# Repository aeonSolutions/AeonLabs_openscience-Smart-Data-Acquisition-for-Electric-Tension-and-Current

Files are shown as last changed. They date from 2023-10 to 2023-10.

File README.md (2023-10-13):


  
 
 

<a href="https://trackgit.com">
trackgit-views
</a>




[](https://www.buymeacoffee.com/migueltomas)

[PCB-Prototyping-Catalogue](https://github.com/aeonSolutions/PCB-Prototyping-Catalogue)  >>  [Laboratory Automation](https://github.com/aeonSolutions/PCB-Prototyping-Catalogue/tree/main/Laboratory%20Automation)  >>  Smart Data Acquisition for Electric Tension and Current

<br>

# Smart Data Acquisition for Electric Tension and Current
This is the repository for revision "11-2023" of the 16-bit Smart DAQ Device with a unique data fingerprint able to do experimental data upload to any data repository. This data acquisition device has oboard the INA237 IC and is suited for electric current measurements (amperage) and also electric tension (voltage) from an external power source. This IC from Texas Instruments is an ultra-precise digital power monitor with a 16-bit delta-sigma ADC specifically designed for current-sensing applications with common-mode voltage support from –0.3 V to +85 V. For more detailed information about this IC, see the datasheet [here](https://www.ti.com/product/INA237).

<p align="center">
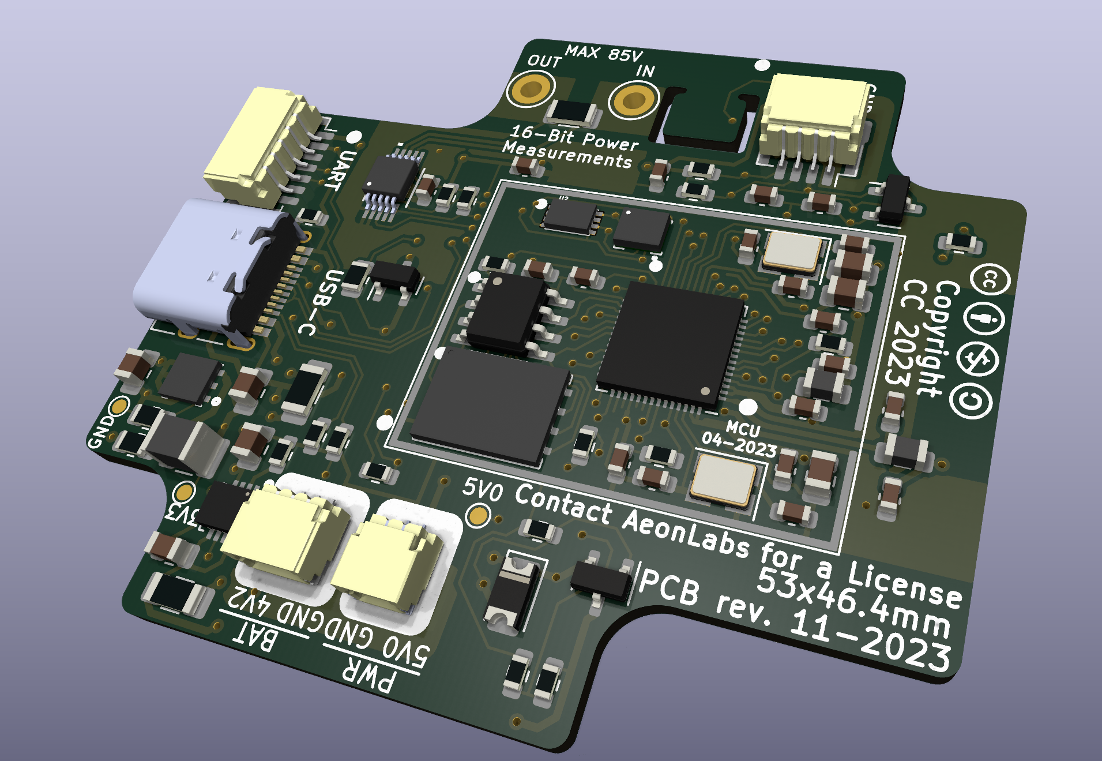
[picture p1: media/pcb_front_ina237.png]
   
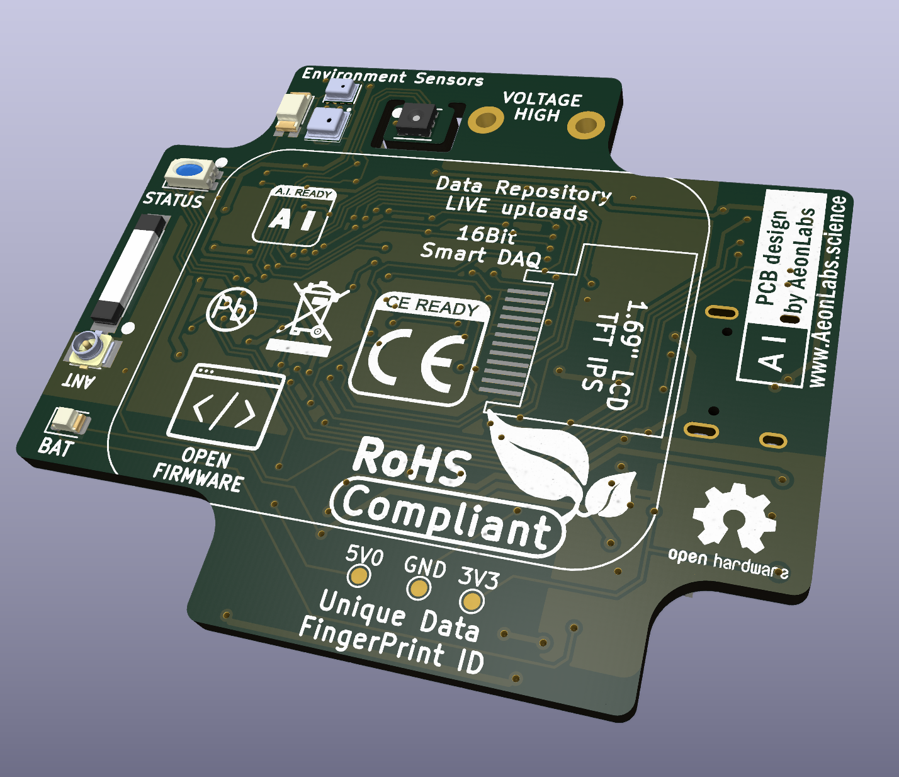
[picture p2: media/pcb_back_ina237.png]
   
</p>

<br>

### Circuit Schematic
The circuit schematic for this smart DAQ can be found on the folder "circuit schematic" [here](https://github.com/aeonSolutions/AeonLabs_openscience-Smart-Data-Acquisition-for-Electric-Tension-and-Current/tree/main/Circuit%20Schematic). 
<p align="center">
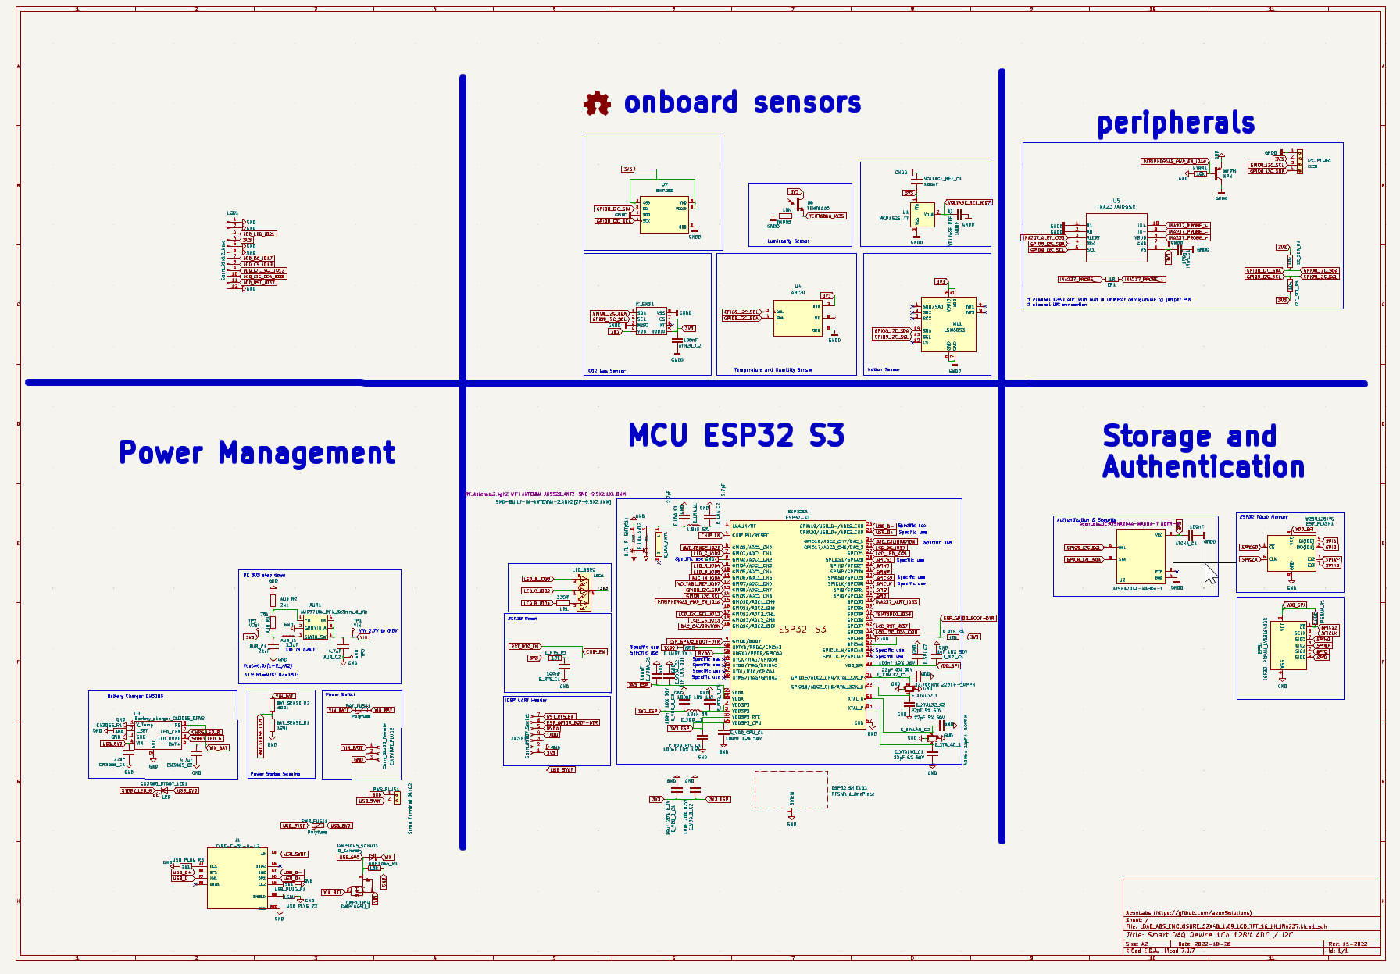
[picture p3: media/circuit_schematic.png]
   
</p>

<br>

### Q & A
If you have a question and looking for an answer, there's a **Discussions** chat on the menu above.  Here's the [link](https://github.com/aeonSolutions/AeonLabs_openscience-Smart-Data-Acquisition-for-Electric-Tension-and-Current/discussions). You can post any question related to any of the Smart Data Acquisition devices and Experimental Setups.

<br>

### Known Experimental Tests
This smart data acquisition devices is compatible for the following laboratory experimental tests:

#### [NT Build 492](http://www.nordtest.info/wp/1999/11/21/concrete-mortar-and-cement-based-repair-materials-chloride-migration-coefficient-from-non-steady-state-migration-experiments-n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): Concrete, mortar and cement-based repair materials: Chloride migration coefficient from non-steady-state migration experiments

<p align="center">
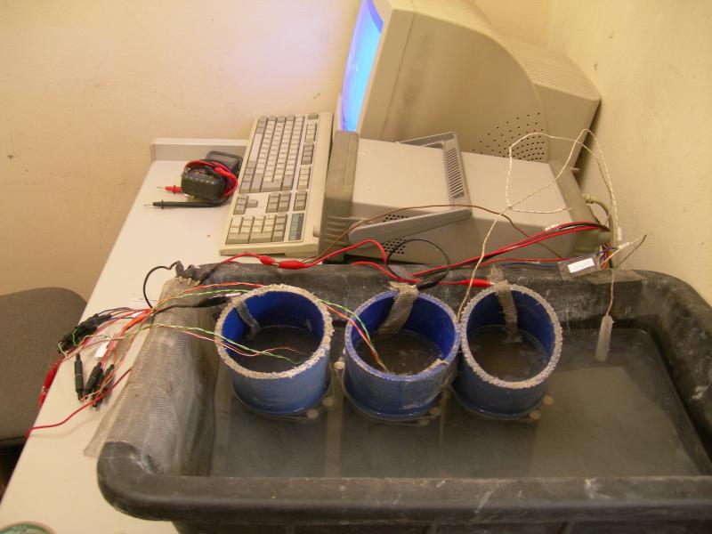
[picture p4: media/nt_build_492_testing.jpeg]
   
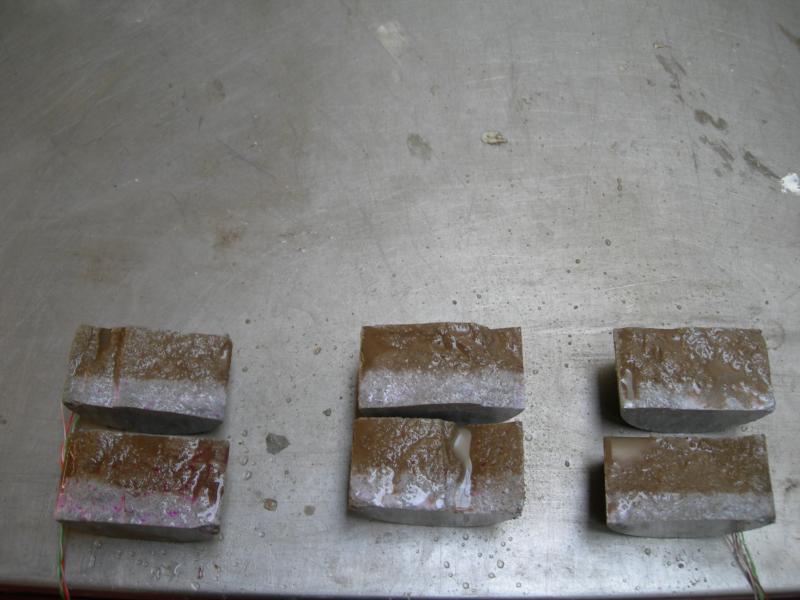
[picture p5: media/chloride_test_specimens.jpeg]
   
</p>

See [here](https://github.com/aeonSolutions/Open-Scientific-Research/wiki/Rapid-Chloride-Migration-Test-(NT-Build-492)) a description of this experimental test procedure using the NT Build 492. 

<br>
  
#### other tests ...

<br>
<br>
 
## Compatibility

<p align="center">
 <a href"https://www.apple.com/shop/accessories/all/homekit">

 </a>
<a href="https://home.google.com"> 
 
 </a>
<a href="https://www.home-assistant.io">  
 
 </a>
<a href="https://csa-iot.org/all-solutions/matter/">  
 
 </a>
<a href="https://csa-iot.org/all-solutions/matter/">  
 
 </a>
</p>

<br>

## What one additionally needs
- [USB to UART/USB TTL firmware burner for 5V and 3.3V MCUs ](https://github.com/aeonSolutions/PCB-Prototyping-Catalogue/blob/main/DIY-Maker/README.md)
- [Upgradable ESP32 MCU](https://github.com/aeonSolutions/AeonLabs-Upgradable-MCU-ESP32)

<br />
<br />

**Get a Notification on every PCB update**

| [](https://www.tindie.com/stores/aeonlabs/) | You can fill in your [email here (Google form)](https://docs.google.com/forms/d/e/1FAIpQLScErMgQYRdA-umvCjvTPPrCO7Lg1QYowTxb7vfa8cTfrcPEAA/viewform?usp=pp_url) and I'll send a reminder when a new PCB prototype is made available here or a new revision for an existing PCB. Stay tuned! |
|---|---|

<br>
<br>

## Author

You can get in touch with me on my LinkedIn Profile:

#### Miguel Tomas



You can also follow my GitHub Profile to stay updated about my latest projects: 

**Hire me**

If you like my work here and are looking to design and deploy your own smart device you can hire me on:

- [Fiverr](https://www.fiverr.com/s/GjmPxe). The price starts at $25
- [Guru](https://www.guru.com/freelancers/miguel-tomas)
  
<br>

### Be supportive of my dedication and work towards technology education and buy me a cup of coffee
The PCB Desgin Files i provide here for anyone to use are free. If you like this Smart Device or use it, please consider buying me a cup of coffee, a slice of pizza or a book to help me study, eat and think new PCB design files.

[](https://www.buymeacoffee.com/migueltomas)

<br />

### Make a donation on Paypal
Make a donation on paypal and get a TAX refund*.

(http://paypal.me/mtpsilva)

<br>

### Support all these open hardware projects and become a patreon  
Liked any of my PCB KiCad Designs? Help and Support my open work to all by becomming a LDAD Patreon.
In return I will give a free PCB design in KiCad to all patreon supporters. To learn more go to patreon.com. Link below.

(https://www.patreon.com/ldad)

<br />
<br />

______________________________________________________________________________________________________________________________
### License

Before proceeding to download any of AeonLabs software solutions for open-source development and/or PCB hardware electronics development make sure you are choosing the right license for your project. See [AeonLabs Solutions for Open Hardware & Source Development](https://github.com/aeonSolutions/PCB-Prototyping-Catalogue/wiki/AeonLabs-Solutions-for-Open-Hardware-&-Source-Development) for more information.

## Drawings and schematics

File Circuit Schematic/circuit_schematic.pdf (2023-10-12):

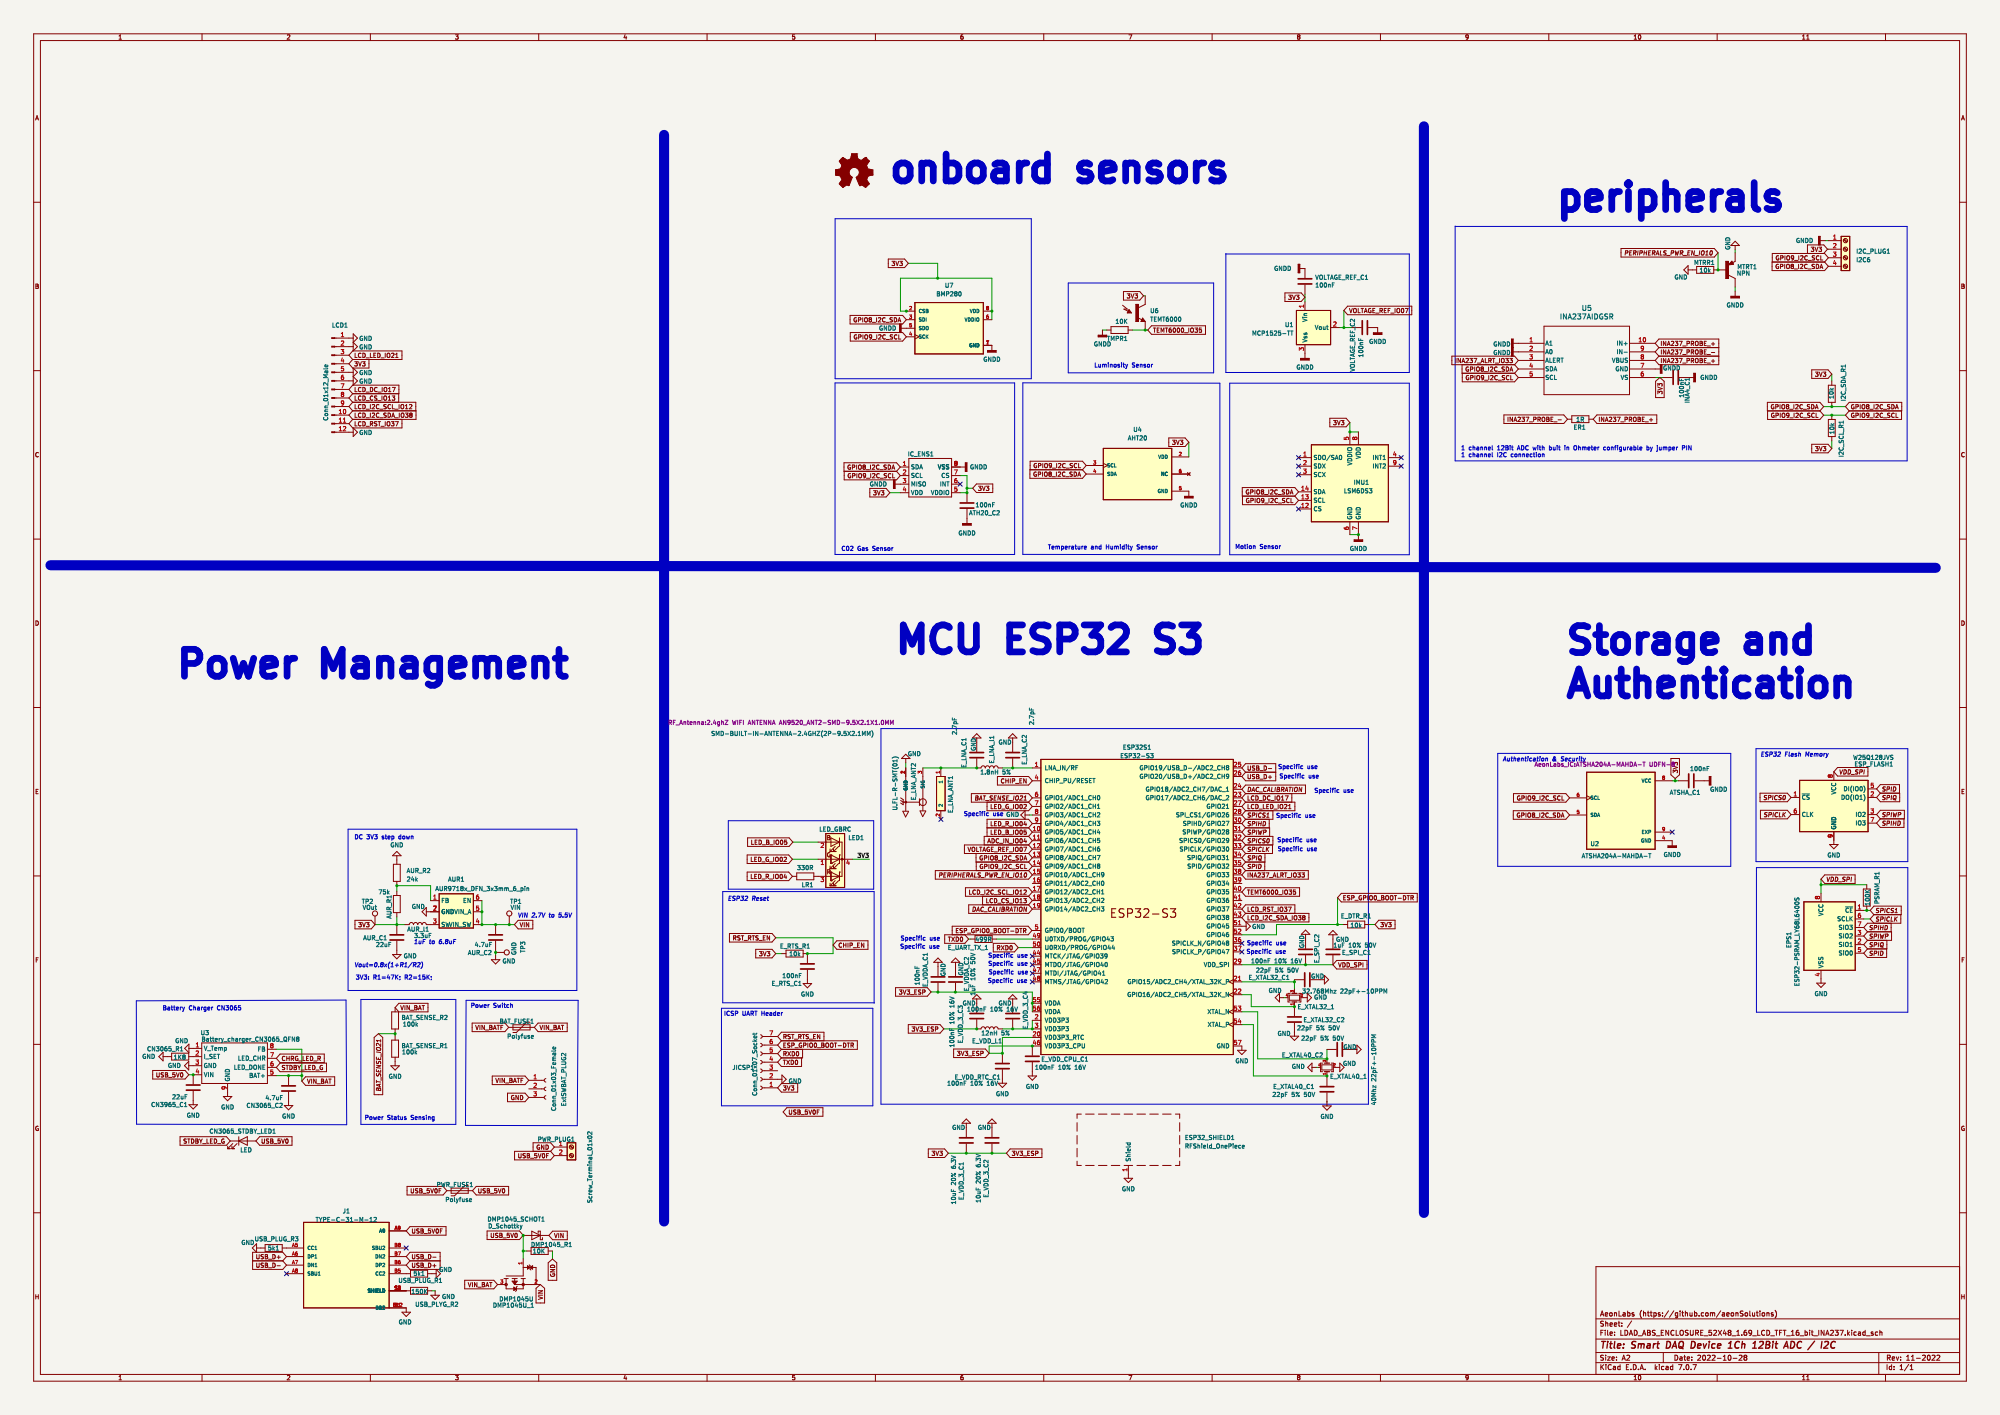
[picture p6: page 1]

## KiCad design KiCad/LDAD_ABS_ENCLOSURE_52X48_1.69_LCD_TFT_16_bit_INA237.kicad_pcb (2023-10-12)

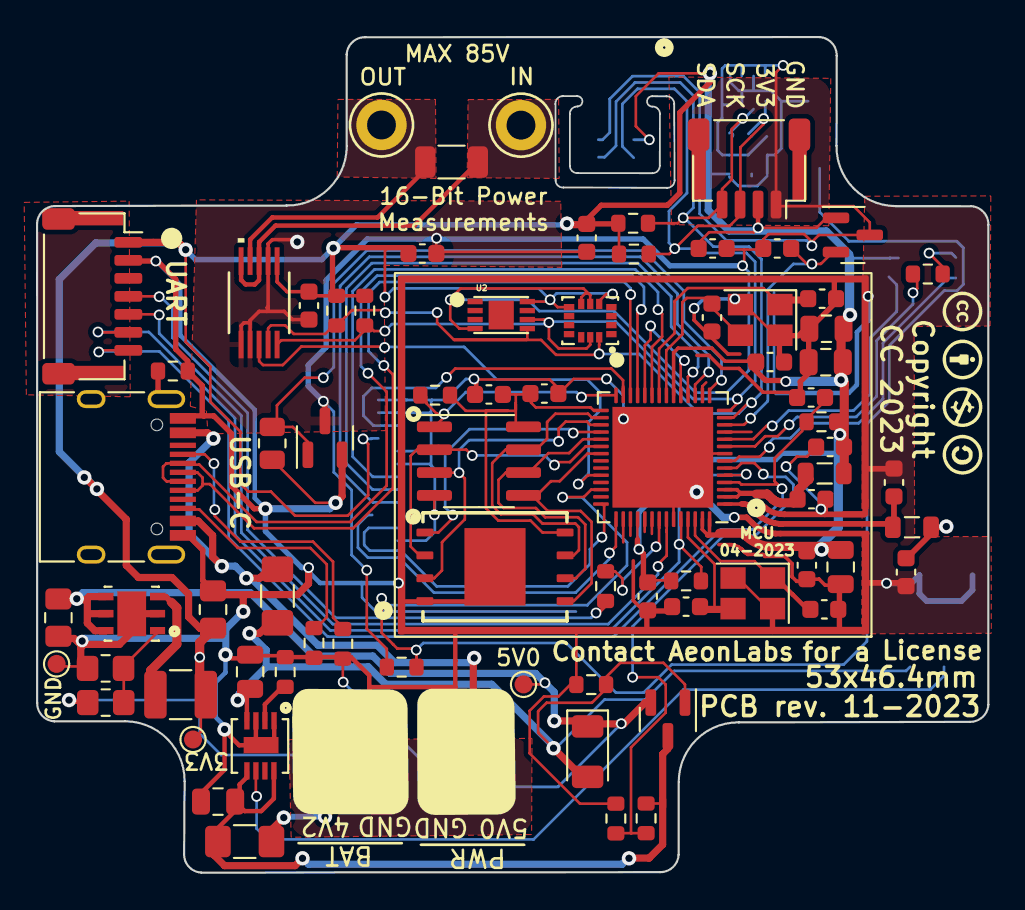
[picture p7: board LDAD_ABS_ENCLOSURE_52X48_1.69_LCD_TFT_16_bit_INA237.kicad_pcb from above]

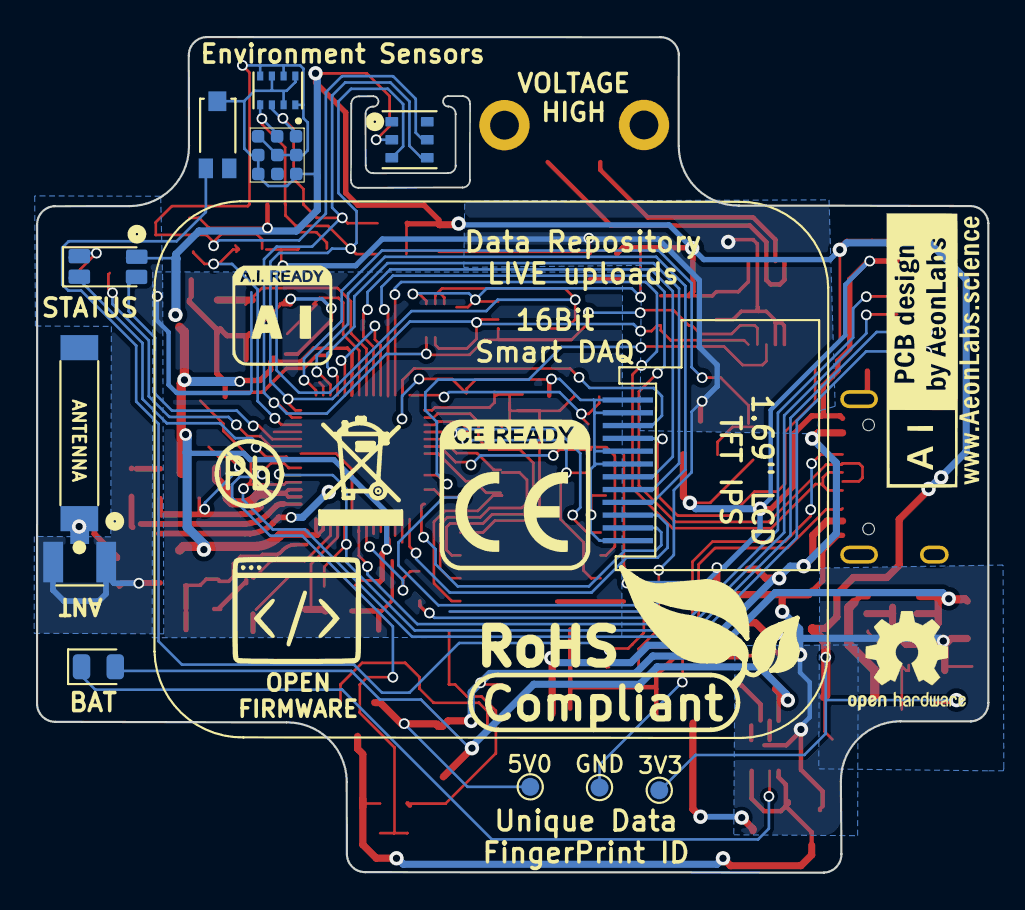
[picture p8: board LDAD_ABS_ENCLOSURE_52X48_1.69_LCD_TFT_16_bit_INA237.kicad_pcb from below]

Board: 2 copper layers, 52.9 x 46.4 mm, 90 parts (15 on the bottom side), 57 nets.

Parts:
ATH20_C2: 100nF; C_0603_1608Metric
ATSHA_C1: 100nF; C_0603_1608Metric
AUR1: AUR9718x_DFN_3x3mm_6_pin; AUR9718 ST1S09 SON95P300X300X100-7N
AUR_C1: 22uF; C_0805_2012Metric_Pad1.18x1.45mm_HandSolder
AUR_C2: 4.7uF; C_0805_2012Metric_Pad1.18x1.45mm_HandSolder
AUR_R1: 75k; R_0805_2012Metric_Pad1.20x1.40mm_HandSolder
AUR_R2: 24k; R_0805_2012Metric_Pad1.20x1.40mm_HandSolder
AUR_l1: 3.3uF; L_1210_3225Metric
BAT_FUSE1: Polyfuse; Fuse_1206_3216Metric_Pad1.42x1.75mm_HandSolder
BAT_SENSE_R1, BAT_SENSE_R2: 100k; R_0603_1608Metric
CN3065_C2: 4.7uF; C_0805_2012Metric
CN3065_R1: 1K8; R_0603_1608Metric
CN3065_STDBY_LED1: LED; LED_0805_2012Metric
CN3965_C1: 22uF; C_0805_2012Metric
DMP1045U_1: DMP1045U; SOT-23
DMP1045_R1: 10K; R_0603_1608Metric
DMP1045_SCHOT1: D_Schottky; D_1206_3216Metric
EPS1: ESP32-PSRAM_LY68L6400S; SOIC-8_3.9x4.9mm_P1.27mm
ER1: 1R; R_1206_3216Metric
ESP32S1: ESP32-S3; QFN-56-1EP_7x7mm_P0.4mm_EP5.6x5.6mm
ESP32_SHIELD1: RFShield_OnePiece; ESP32-S3 GND Shield
ESP_FLASH1: W25Q128JVS; WSON8 FLASH SPI SON127P800X600X80-9N
E_DTR_R1: 10k; R_0603_1608Metric
E_LNA_ANT1: AN9520; 2.4ghZ WIFI ANTENNA AN9520_ANT2-SMD-9.5X2.1X1.0MM
E_LNA_ANT2: U.FL-R-SMT(01); RF Antenna IPEX SMD PCB HRS_U.FL-R-SMT(01)
E_LNA_C1, E_LNA_C2: 2.7pF; C_0603_1608Metric
E_LNA_l1: 1.8nH 5%; L_0805_2012Metric
E_RTS_C1: 100nF; C_0603_1608Metric
E_RTS_R1: 10k; R_0603_1608Metric
E_SPI_C1: 1uF 10% 50V; C_0603_1608Metric
E_SPI_C2: 100nF 10% 16V; C_0603_1608Metric
E_UART_TX_1: 499R; R_0603_1608Metric
E_VDDA_C1: 100nF; C_0603_1608Metric
E_VDDA_C2: 1uF 10% 50V; C_0805_2012Metric
E_VDD_3_C1, E_VDD_3_C2: 10uF 20% 6.3V; C_0805_2012Metric
E_VDD_3_C3, E_VDD_3_C4: 100nF 10% 16V; C_0603_1608Metric
E_VDD_CPU_C1: 100nF 10% 16V; C_0603_1608Metric
E_VDD_L1: 12nH 5%; L_0805_2012Metric
E_VDD_RTC_C1: 100nF 10% 16V; C_0603_1608Metric
E_XTAL32_1: 32.768Mhz 22pF+-10PPM; Crystal_SMD_3225-4Pin_3.2x2.5mm
E_XTAL32_C1, E_XTAL32_C2, E_XTAL40_C1, E_XTAL40_C2: 22pF 5% 50V; C_0603_1608Metric
E_XTAL40_1: 40Mhz 22pF+-10PPM; Crystal_SMD_3225-4Pin_3.2x2.5mm
ExtSWBAT_PLUG2: Conn_01x03_Female; JST_SH_SM03B-SRSS-TB_1x03-1MP_P1.00mm_Horizontal
I2C_PLUG1: I2C6; JST_SH_SM04B-SRSS-TB_1x04-1MP_P1.00mm_Horizontal
I2C_SCL_R1, I2C_SDA_R1: 10k; R_0603_1608Metric
IC_ENS1: ENS160 Gas Semsor
IMR1, IMR2: 10K; R_0603_1608Metric
IMU1: LSM6DS3; LSM6DS3 Motion Sensor PQFN50P300X250X86-14N
INA4_C1: 100nF; C_0603_1608Metric
J1: TYPE-C-31-M-12; USB_C_Receptacle_HRO_TYPE-C-31-M-12
JICSP1: Conn_01x07_Socket; JST_SH_SM07B-SRSS-TB_1x07-1MP_P1.00mm_Horizontal
LCD1: Conn_01x12_Male; 1,69 inch LCD IPS TFT
LED1: LED_GBRC; LED_1206_3210_RGB_Metric
LR1: 330R; R_0603_1608Metric
MTRR1: 10k; R_0805_2012Metric
MTRT1: NPN; SOT-23
PSRAM_R1: 100K; R_0603_1608Metric
PWR_FUSE1: Polyfuse; Fuse_1206_3216Metric_Pad1.42x1.75mm_HandSolder
PWR_PLUG1: Screw_Terminal_01x02; JST_SH_SM02B-SRSS-TB_1x02-1MP_P1.00mm_Horizontal
Sign-PbFree: LOGO_PBFREE
Sign-RecycleBin: LOGO_RECYCLEBIN_1
Sign-RoHS: LOGO_ROHS_1
TMPR1: 10K; R_0603_1608Metric
TP1, TP1#2: VIN; TestPoint_Pad_D1.0mm
TP2, TP2#2: VOut; TestPoint_Pad_D1.0mm
TP3, TP3#2: GND; TestPoint_Pad_D1.0mm
U1: MCP1525-TT; SOT-23
U2: ATSHA204A-MAHDA-T; ATSHA204A-MAHDA-T UDFN-8
U3: Battery_charger_CN3065_QFN8; QFN8 3.1x2.9mm QFNn-8 3x3 SON80P400X400X100-9N
U4: AHT20; AHT20 HT Sensor PSON100P300X300X110-6N
U5: INA237AIDGSR; INA237
U6: TEMT6000; TEMT6000-SEN
U7: BMP280; XDCR_BMP280
USB_PLUG_R1, USB_PLUG_R3: 5k1; R_0603_1608Metric
USB_PLYG_R2: 150K; R_0603_1608Metric
VOLTAGE_REF_C1, VOLTAGE_REF_C2: 100nF; C_0603_1608Metric

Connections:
3V3: ATH20_C2.2, ATSHA_C1.2, AUR_C1.1, AUR_R1.1, AUR_l1.1, ESP32S1.20 (VDD3P3_RTC), ESP32S1.46 (VDD3P3_CPU), ESP32S1.55 (VDDA), ESP32S1.56 (VDDA), E_DTR_R1.1, E_RTS_R1.1, E_VDDA_C1.2, E_VDDA_C2.2, E_VDD_3_C1.1, E_VDD_3_C2.1, E_VDD_3_C3.1, E_VDD_CPU_C1.1, E_VDD_L1.1, E_VDD_RTC_C1.1, I2C_PLUG1.2, I2C_SCL_R1.1, I2C_SDA_R1.2, IC_ENS1.4 (VDD), IC_ENS1.5 (VDDIO), IC_ENS1.7 (CS), IMR1.1, IMR2.1, IMU1.5 (VDDIO), IMU1.8 (VDD), INA4_C1.2, JICSP1.1, LCD1.4, LED1.4 (K), TP2.1, TP2#2.1, U1.1 (Vin), U2.8 (VCC), U4.2 (VDD), U5.6 (VS), U6.COLLECTOR, U7.2 (CSB), U7.6 (VDDIO), U7.8 (VDD), VOLTAGE_REF_C1.2
BAT_SENSE_IO21: BAT_SENSE_R1.1, BAT_SENSE_R2.2, ESP32S1.6 (GPIO1/ADC1_CH0)
CHIP_EN: ESP32S1.4 (CHIP_PU/RESET), E_RTS_C1.2, E_RTS_R1.2, JICSP1.7
DAC_CALIBRATION: ESP32S1.19 (GPIO14/ADC2_CH3), ESP32S1.24 (GPIO18/ADC2_CH7/DAC_1)
ESP_GPIO0_BOOT-DTR: ESP32S1.5 (GPIO0/BOOT), ESP32S1.52 (GPIO46), E_DTR_R1.2, JICSP1.6
GND: AUR1.2 (GND), AUR1.7 (GND), AUR_C1.2, AUR_C2.2, AUR_R2.2, BAT_SENSE_R1.2, CN3065_C2.1, CN3065_R1.1, CN3965_C1.1, DMP1045_R1.2, EPS1.4 (VSS), ESP32S1.8 (GPIO3/ADC1_CH2), ESP32S1.51 (GPIO45), ESP32S1.57 (GND), ESP32_SHIELD1.1 (Shield), ESP_FLASH1.4 (GND), ESP_FLASH1.9 (GND), E_LNA_ANT2.1 (GND), E_LNA_ANT2.2 (GND), E_LNA_C1.2, E_LNA_C2.2, E_RTS_C1.1, E_SPI_C1.2, E_SPI_C2.2, E_VDDA_C1.1, E_VDDA_C2.1, E_VDD_3_C1.2, E_VDD_3_C2.2, E_VDD_3_C3.2, E_VDD_3_C4.2, E_VDD_CPU_C1.2, E_VDD_RTC_C1.2, E_XTAL32_1.2, E_XTAL32_1.4, E_XTAL32_C1.2, E_XTAL32_C2.2, E_XTAL40_1.2, E_XTAL40_1.4, E_XTAL40_C1.2, E_XTAL40_C2.2, ExtSWBAT_PLUG2.3, J1.B1, J1.B12, JICSP1.2, LCD1.1, LCD1.2, LCD1.5, LCD1.6, LCD1.12, MTRR1.1, MTRT1.2, PWR_PLUG1.1, TP3.1, TP3#2.1, U3.1 (V_Temp), U3.3 (GND), U3.9 (GND), USB_PLUG_R1.2, USB_PLUG_R3.2, USB_PLYG_R2.2
GNDD: ATH20_C2.1, ATSHA_C1.1, I2C_PLUG1.1, IC_ENS1.3 (MISO), IC_ENS1.8 (VSS), IC_ENS1.9 (VSS), IMU1.6 (GND), IMU1.7 (GND), INA4_C1.1, MTRT1.3, TMPR1.1, U1.3 (Vss), U2.4 (GND), U4.5 (GND), U5.1 (A1), U5.2 (A0), U5.7 (GND), U7.1 (GND), U7.5 (SDO), U7.7 (GND), VOLTAGE_REF_C1.1, VOLTAGE_REF_C2.1
GPIO8_I2C_SDA: ESP32S1.13 (GPIO8/ADC1_CH7), I2C_PLUG1.4, I2C_SDA_R1.1, IC_ENS1.1 (SDA), IMR1.2, IMU1.14 (SDA), U2.5 (SDA), U4.4 (SDA), U5.4 (SDA), U7.3 (SDI)
GPIO9_I2C_SCL: ESP32S1.14 (GPIO9/ADC1_CH8), I2C_PLUG1.3, I2C_SCL_R1.2, IC_ENS1.2 (SCL), IMR2.2, IMU1.13 (SCL), U2.6 (SCL), U4.3 (SCL), U5.5 (SCL), U7.4 (SCK)
INA237_ALRT_IO33: ESP32S1.38 (GPIO33), U5.3 (ALERT)
INA237_PROBE_+: ER1.2, U5.8 (VBUS), U5.10 (IN+)
INA237_PROBE_-: ER1.1, U5.9 (IN-)
LCD_CS_IO13: ESP32S1.18 (GPIO13/ADC2_CH2), LCD1.8
LCD_DC_IO17: ESP32S1.23 (GPIO17/ADC2_CH6/DAC_2), LCD1.7
LCD_I2C_SCL_IO12: ESP32S1.17 (GPIO12/ADC2_CH1), LCD1.9
LCD_I2C_SDA_IO38: ESP32S1.43 (GPIO38), LCD1.10
LCD_LED_IO21: ESP32S1.27 (GPIO21), LCD1.3
LCD_RST_IO37: ESP32S1.42 (GPIO37), LCD1.11
LED_B_IO05: ESP32S1.10 (GPIO5/ADC1_CH4), LED1.2 (BA)
LED_G_IO02: ESP32S1.7 (GPIO2/ADC1_CH1), LED1.1 (GA)
LED_R_IO04: ESP32S1.9 (GPIO4/ADC1_CH3), LR1.1
unnamed: AUR1.1 (FB), AUR_R1.2, AUR_R2.1
unnamed: AUR1.3 (SW), AUR_l1.2
unnamed: ESP32S1.21 (GPIO15/ADC2_CH4/XTAL_32K_P), E_XTAL32_1.3, E_XTAL32_C1.1
unnamed: ESP32S1.22 (GPIO16/ADC2_CH5/XTAL_32K_N), E_XTAL32_1.1, E_XTAL32_C2.1
unnamed: ESP32S1.1 (LNA_IN/RF), E_LNA_C2.1, E_LNA_l1.2
unnamed: ESP32S1.49 (U0TXD/PROG/GPIO43), E_UART_TX_1.2
unnamed: ESP32S1.2 (VDD3P3), ESP32S1.3 (VDD3P3), E_VDD_3_C4.1, E_VDD_L1.2
unnamed: ESP32S1.53 (XTAL_N), E_XTAL40_1.3, E_XTAL40_C2.1
unnamed: ESP32S1.54 (XTAL_P), E_XTAL40_1.1, E_XTAL40_C1.1
unnamed: E_LNA_ANT1.1, E_LNA_ANT2.3 (SIG), E_LNA_C1.1, E_LNA_l1.1
unnamed: J1.A5 (CC1), USB_PLUG_R3.1
unnamed: J1.B5 (CC2), USB_PLUG_R1.1
unnamed: J1.S1 (SHIELD), USB_PLYG_R2.1
unnamed: LED1.3 (RA), LR1.2
unnamed: CN3065_R1.2, U3.2 (I_SET)
PERIPHERALS_PWR_EN_IO10: ESP32S1.15 (GPIO10/ADC1_CH9), MTRR1.2, MTRT1.1
RXD0: ESP32S1.50 (U0RXD/PROG/GPIO44), JICSP1.5
SPICLK: EPS1.6 (SCLK), ESP32S1.33 (SPICLK/GPIO30), ESP_FLASH1.6 (CLK)
SPICS0: ESP32S1.32 (SPICS0/GPIO29), ESP_FLASH1.1 (~CS)
SPICS1: EPS1.1 (~CE), ESP32S1.28 (SPI_CS1/GPIO26), PSRAM_R1.1
SPID: EPS1.5 (SiO0), ESP32S1.35 (SPID/GPIO32), ESP_FLASH1.5 (DI(IO0))
SPIHD: EPS1.7 (SIO3), ESP32S1.30 (SPIHD/GPIO27), ESP_FLASH1.7 (IO3)
SPIQ: EPS1.2 (SIO1), ESP32S1.34 (SPIQ/GPIO31), ESP_FLASH1.2 (DO(IO1))
SPIWP: EPS1.3 (SIO2), ESP32S1.31 (SPIWP/GPIO28), ESP_FLASH1.3 (IO2)
STDBY_LED_G: CN3065_STDBY_LED1.1 (K), U3.6 (LED_DONE)
TEMT6000_IO35: ESP32S1.40 (GPIO35), TMPR1.2, U6.EMITTER
TXD0: E_UART_TX_1.1, JICSP1.4
USB_5V0: CN3065_STDBY_LED1.2 (A), CN3965_C1.2, DMP1045U_1.1, DMP1045_R1.1, DMP1045_SCHOT1.2 (A), PWR_FUSE1.1, U3.4 (VIN)
USB_5V0F: J1.A4, J1.A9, PWR_FUSE1.2, PWR_PLUG1.2
USB_D+: ESP32S1.26 (GPIO20/USB_D+/ADC2_CH9), J1.A6 (DP1), J1.B6 (DP2)
USB_D-: ESP32S1.25 (GPIO19/USB_D-/ADC2_CH8), J1.A7 (DN1), J1.B7 (DN2)
VDD_SPI: EPS1.8 (VCC), ESP32S1.29 (VDD_SPI), ESP_FLASH1.8 (VCC), E_SPI_C1.1, E_SPI_C2.1, PSRAM_R1.2
VIN: AUR1.4 (VIN_SW), AUR1.5 (VIN_A), AUR1.6 (EN), AUR_C2.1, DMP1045U_1.2, DMP1045_SCHOT1.1 (K), TP1.1, TP1#2.1
VIN_BAT: BAT_FUSE1.1, BAT_SENSE_R2.1, CN3065_C2.2, DMP1045U_1.3, U3.5 (BAT+), U3.8 (FB)
VIN_BATF: BAT_FUSE1.2, ExtSWBAT_PLUG2.1
VOLTAGE_REF_IO07: ESP32S1.12 (GPIO7/ADC1_CH6), U1.2 (Vout), VOLTAGE_REF_C2.2
